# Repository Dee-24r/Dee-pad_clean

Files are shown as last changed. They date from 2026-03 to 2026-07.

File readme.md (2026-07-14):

This is the clean folder (omiting junk and system files) for https://github.com/Dee-24r/My_Hackpad (which I'm still pushing files to by the way).

# Deepad
I'm currently still assembling my macropad and updating the repo as I do.

## Overview
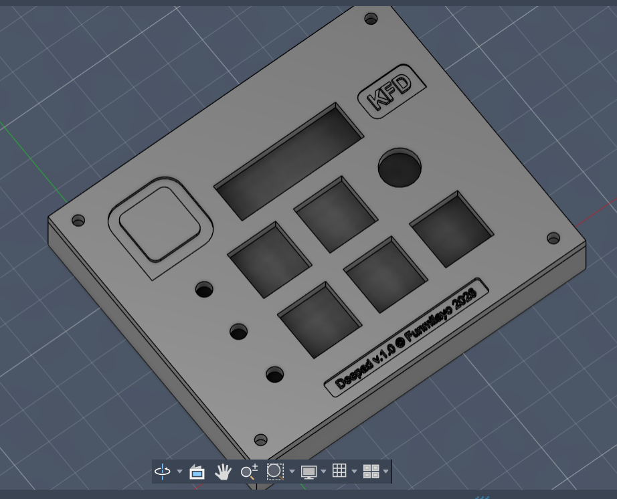
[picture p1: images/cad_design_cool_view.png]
 <br><br>
My macropad contains 5 key switches, a rotary encoder with a switch, an OLED display, and 3 RGB LEDs. It uses the [SEEED Xiao RP2040](https://wiki.seeedstudio.com/XIAO-RP2040/) microcontroller.

## Demo Video
<video width="100%" controls muted playsinline>
	<source src="Macropad%20Demo.mp4" type="video/mp4">
	Your browser does not support embedded video.
</video>

[Macropad Demo.mp4](Macropad%20Demo.mp4)

## Assembly Progress
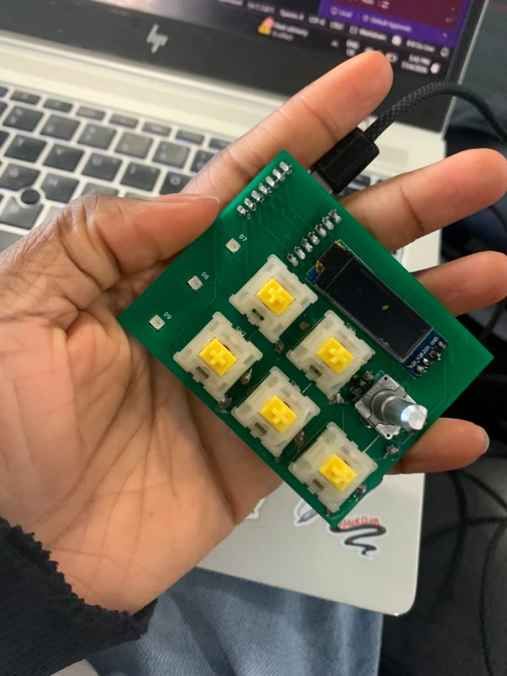
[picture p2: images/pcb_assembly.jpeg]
PCB Assembly

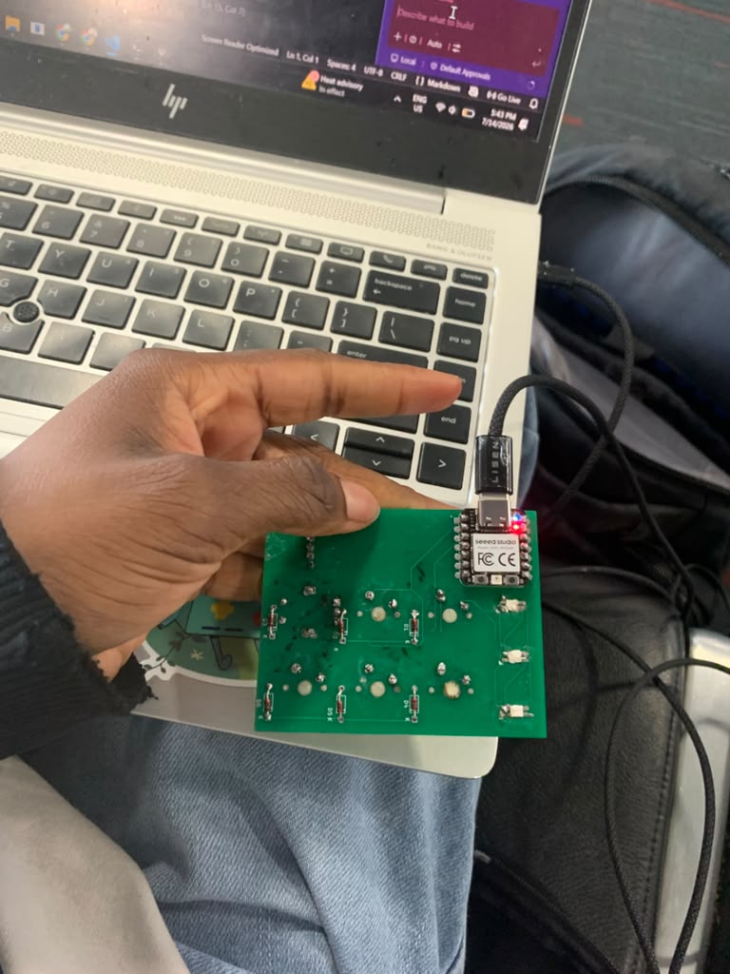
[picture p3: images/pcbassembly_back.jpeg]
PCB Assembly Back


## Repo info

This repo contains the design files (electrical and cad) for deepad v.1.0, :) my macropad. I added the schematic and pcb designs (along with the (custom) symbol and footprint libraries used), the case and pcb cad designs (in .STEP files), gerber files for pcb production (gerber.zip), and the firmware for the macropad. There is also an image folder (If you're scooping around, this is what you should open - it contains screenshots of every important file/design, and so does this README).

[Go to cad files](deepad_cad/)<br>
[Go to firmware](deepad_firmware/)<br>
[Go to schematic and pcb](deepad_sch_and_pcb/)<br>
[View screenshot of all files](images/) This is where you want to go!

## Making my macropad - with pics
I tried to make this to be journal-like cuz I enjoyed doing it. I hope I was detailed enough!

Components I designed it with:
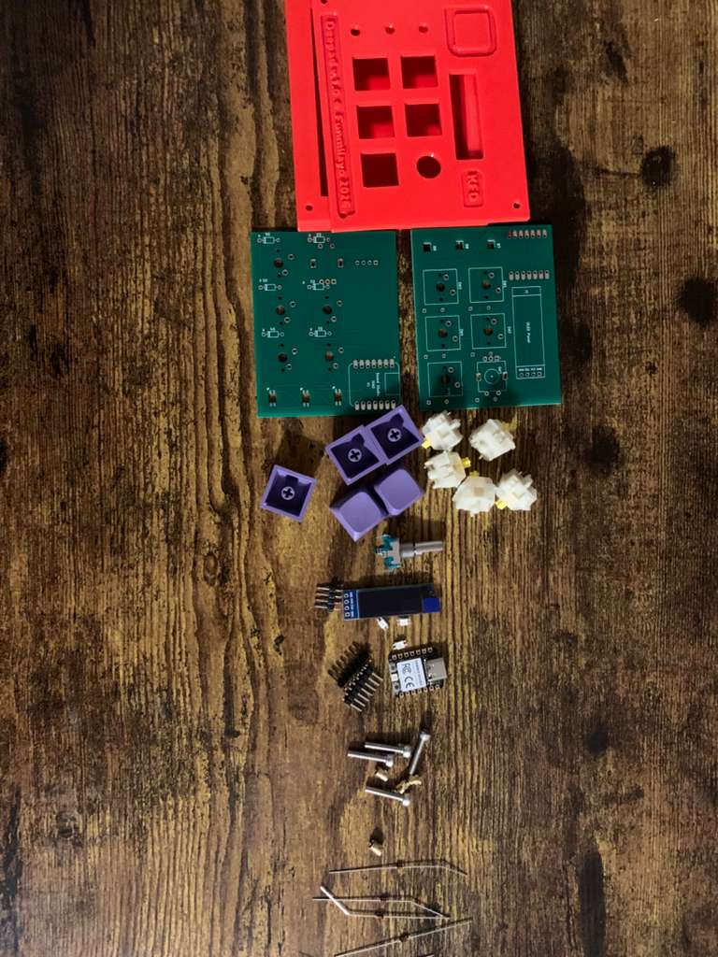
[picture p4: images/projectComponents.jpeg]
Components
 <br><br>

- 1x unsoldered Seeed XIAO RP2040 - the microcontroller
- 5x MX-Style switches - basically keys (keyboard keys)
- 1x EC11 Rotary encoder - it's like a knob and produces rotational value
- 1x 0.91 inch OLED display - display screen
- 5x white blank DSA keycaps - keycaps for the keys
- 3x SK6812 MINI-E LEDs - these are rgb leds
- 4x M3x16mm screws - for screwing my top and bottom case together
- 4x M3x5mx4mm heatset inserts - same as last one - they go together
- 6x 1N4148 diodes -  for the keys

I began by designing the schematic and pcb: added all my components and wired them.

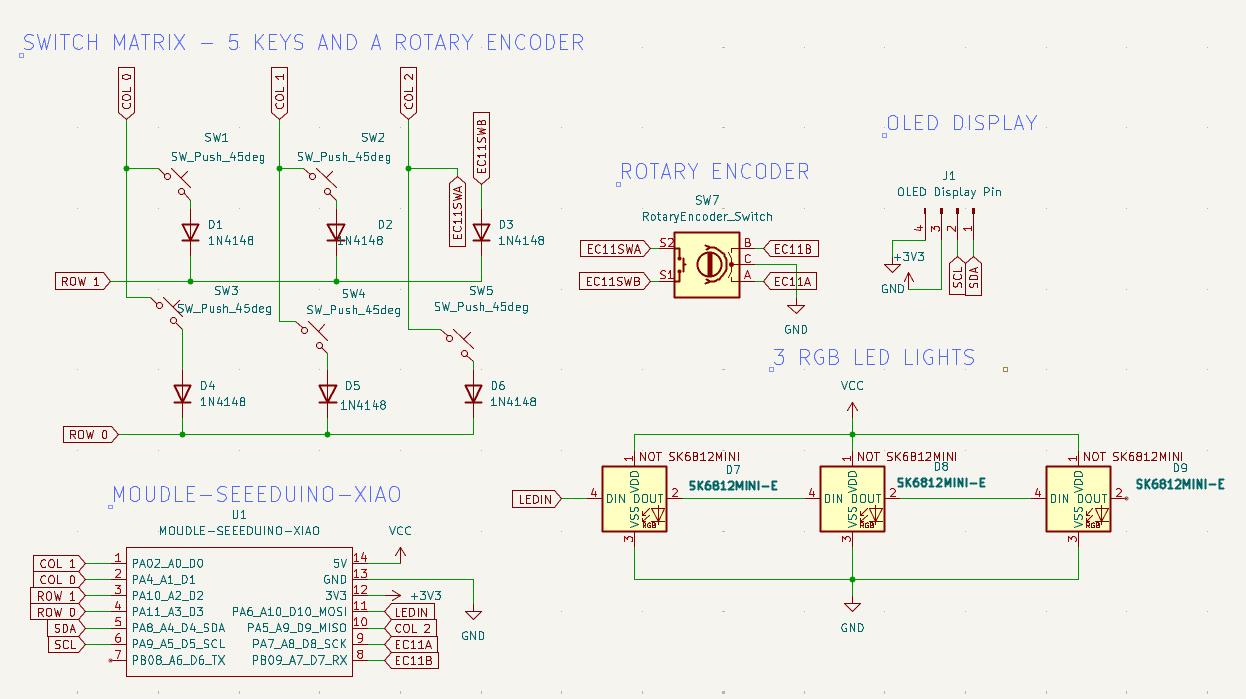
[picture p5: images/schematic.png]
Schematic Screenshot


I assigned footprints and routed the PCB, and learned to use vias. I added edge cuts and exported my STEP file to use in Fusion 360.

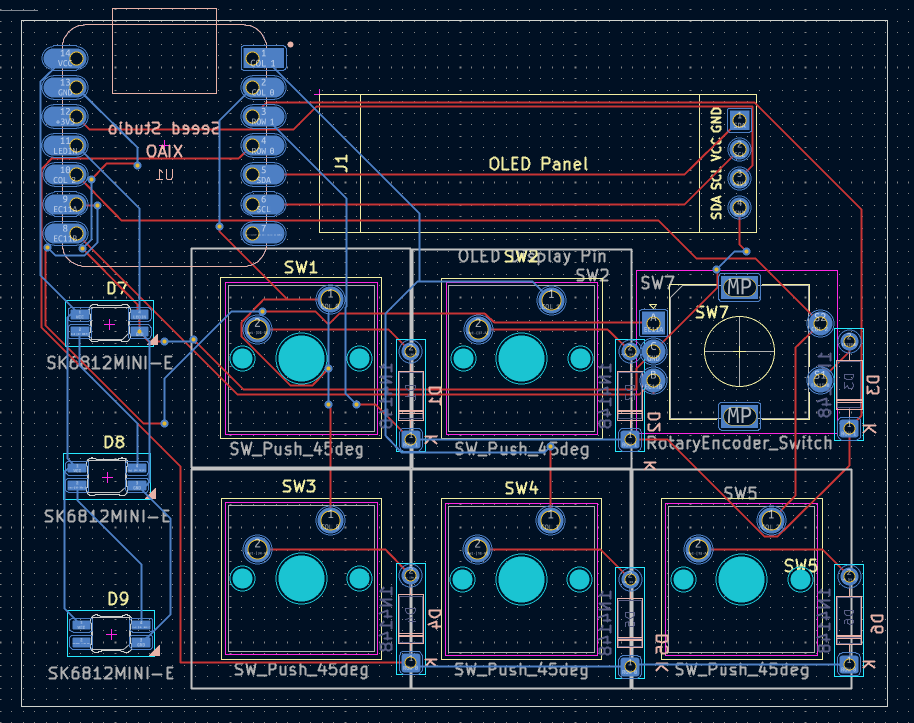
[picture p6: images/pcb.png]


And these are 3d views of the pcb (front and back)

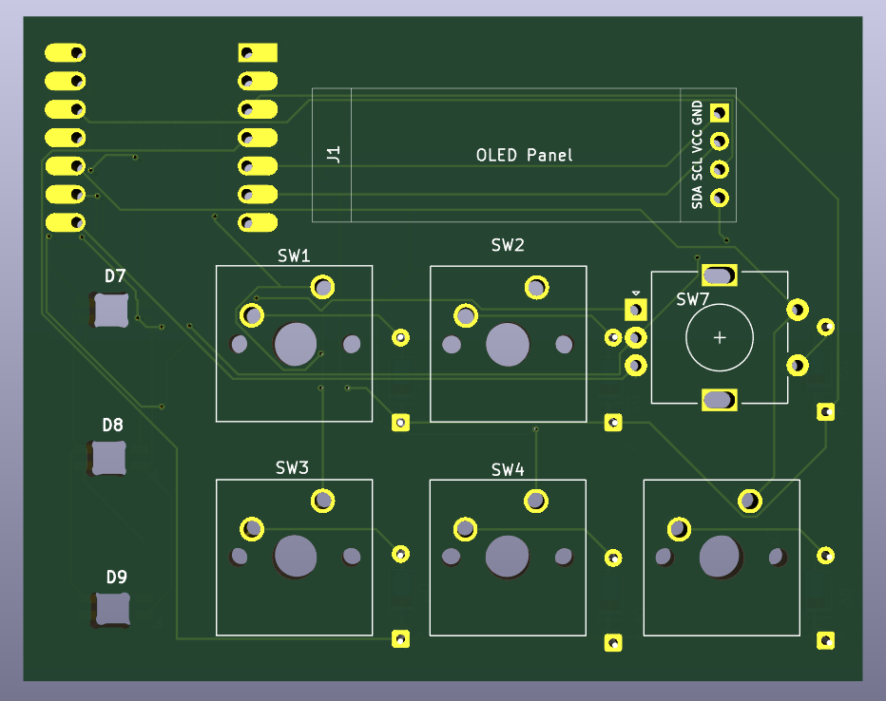
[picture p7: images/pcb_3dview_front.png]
PCB 3d view front Screenshot

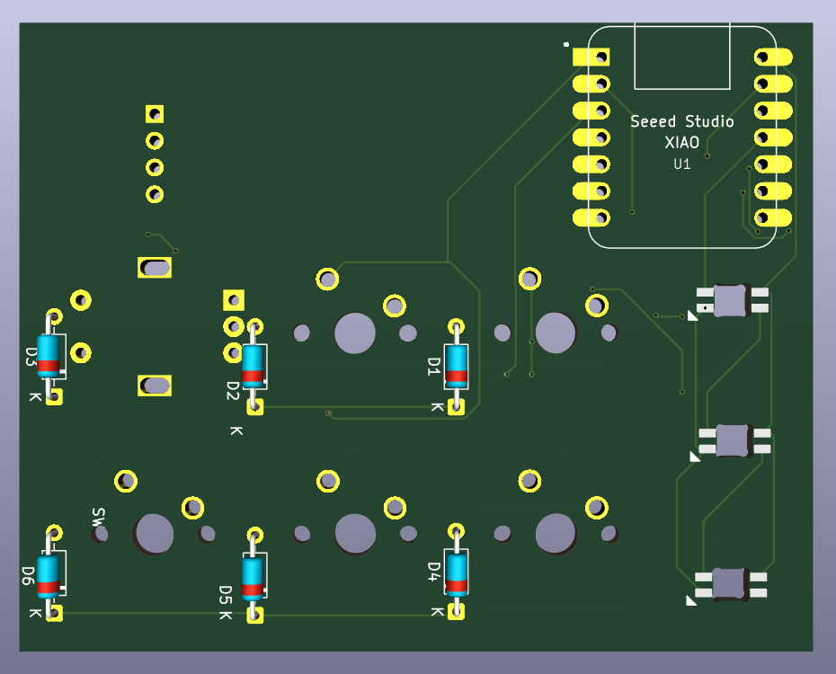
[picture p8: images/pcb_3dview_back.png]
PCB 3d view back Screenshot


BRUH! If you're thinking everything went smooth and step by step, This was not the case! :)

Fusion 360 was a hassle! It's not a bad software; I just didn't know how to use it. But I'm glad I learned.

I started by drawing rectangles for the base of my case, adding holes for the screws and then extruding the shape - outer part of the case is 13mm deep and the inner is 3mm thick. I then attached my PCB .step file to "project" (I had so much trouble understanding how this worked) but got through it anyways. I projected my base case (not recursion :|) to make my top case, which was also 3mm thick. I rounded all my edges a bit and then added the holes for the keys and other components. Finally I added the usb cutout and extruded all holes. I later came back to add a few text decorations to the design (creative enough -- chee!) Here's my full cad design:

CAD screenshot

Next stage was the firmware! You can open up [the firmware folder](deepad_firmware/) to see all the code. It conatins the keyboard.json, rules.mk, config.h, and keymap.c files (keymap.c will still be edited to match my key functions).

I used QMK MSYS to create the folder and then edited the code to match my keys and board. And that was it!

I've soldered most of the parts onto my board. I've actually made more progress after this picture. I'll update the repo later.

Everything I did, I did with the help of many friends in the stasis and blueprint channels, and with much *searching online and asking AI many many many questions*. I'm happy with my work and can't wait to start using it!!

## Macropad use
My first idea for the controls are Git commands in VSCode or any other IDE (e.g. buttons to stage, to commit, push, pull, and more). I plan to have the RGB LEDs indicate information like the status of your branch. Same for the OLED display.

I also would love to see what I can do with this when I hack up a game - (coming soon)! My macropad is made compatible with via, so I'll be using it for many things for sure.

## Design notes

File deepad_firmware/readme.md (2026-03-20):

# deepad
I'm still editing this readme.

Deepad contains 5 keys, a rotary encoder (along with the switch, so we hve 6 switches), 3 rgb leds, and an OLED display. It will be compatible with VIA.

- Keyboard Maintainer: [Oluwafunmilayo Oshebeyo](https://github.com/Dee-24r)
- Processor: RP2040
- Bootloader: rp2040
- Matrix: 2 rows x 3 cols, COL2ROW
- Repository URL: [myHackpad](https://github.com/Dee-24r/myHackpad)

## Features Enabled

- VIA
- OLED (SSD1306)
- RGB Lighting (WS2812)
- Rotary Encoder (with encoder map)
- Media/Mouse key support
- NKRO
 
## Pin Mapping

- Matrix columns: GP27, GP26, GP4
- Matrix rows: GP29, GP28
- Encoder A/B: GP2, GP1
- WS2812 data: GP3 (It's the SK6812MINI-E in the macropad itself)
- OLED I2C SDA/SCL: GP6, GP7

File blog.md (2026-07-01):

## soldering for the first time

Soldering for the rist time and decided to wear shorts for the process :/
Well guess how that went!!

I got my first burn scar on the first day. Anyways, it counts for the experience; scars are a champion's markkks!! (yh sumn lyk that)

I started off by soldering the key/switches (if i remmeber correctly), and thought to myself "is this really necessaryy?"

So, I started soldering the LED's and burnt the back of two. It doesn't affect the connectivity tho!

On my second day of doldering, I melted a part of a socket in the house. Nothing terrible tho, thankfully.

I then soldered the OLED display. When ddesigning a different product 'EDGE' that I needed OLED displays for, I realised that I had designed my OLED display wrongly for the macropad. But I had already soldered the OLED :/

I maybe gave up for a week, thinking the oled would blow up if I soldered the microcontroller. well, I still think that, so I still haven't soldered my micro, which is the only thing currently remaining!!

After a couple weeks, I tried desoldering the OLED with my solder iron. I spent at lest two hours. Even after it looked like all the solder was removed, it was not!! I tried yanking her out, and it didn't work AT ALL!

I hereby am in need of flux!!!! More interestingly I have a highly oxidated :), I have maybe three bridges :) and my joints look like ummmm... :) (see pics). THEREFORE, I AM IN NEED OF FLUXXXX!

More updates coming soon!

#### Here are pics of the soldering statee and details!!
Please, do well to zoon in on the front of the OLED :(

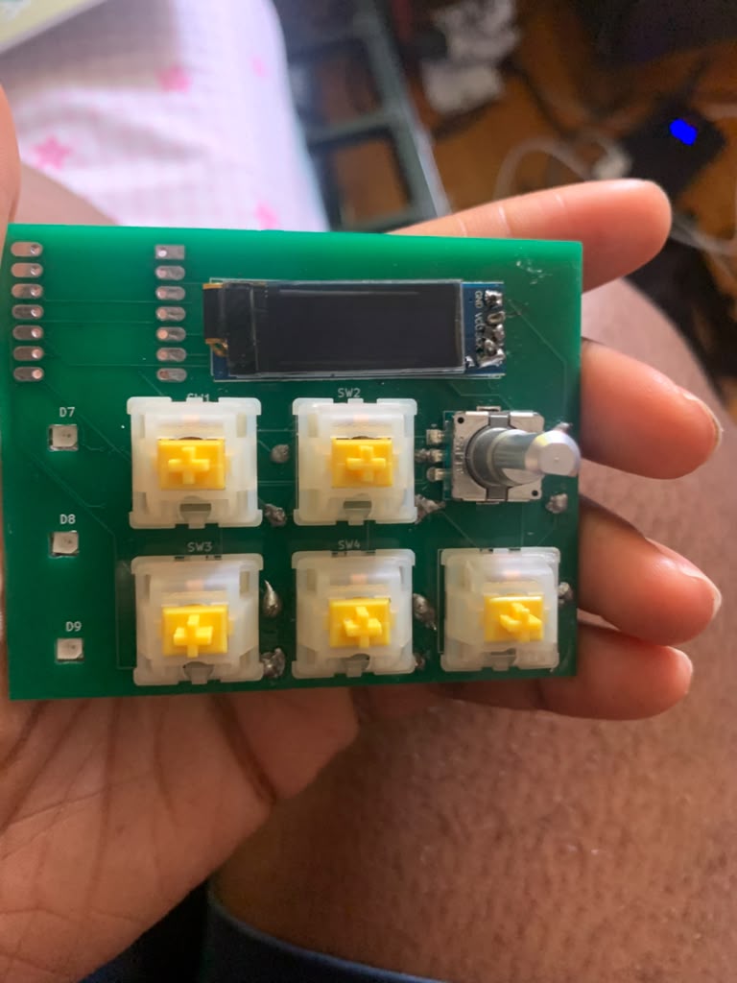
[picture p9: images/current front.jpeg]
Current front


Look at those yummy joints :(
    
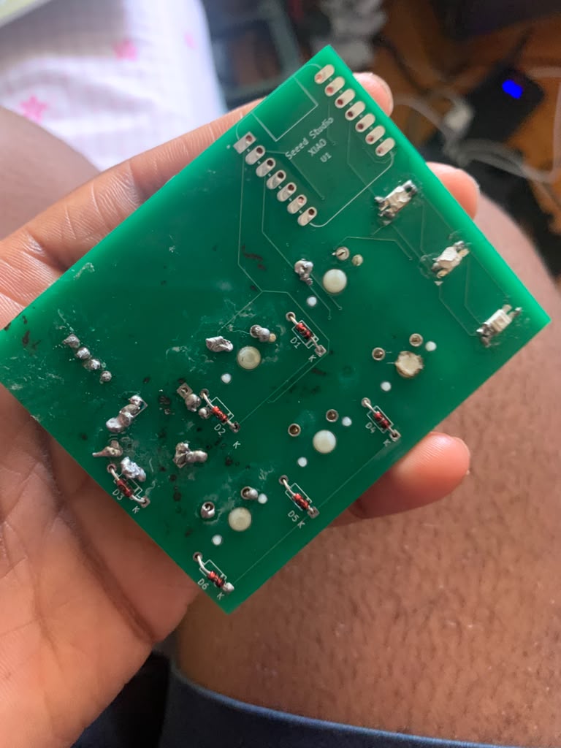
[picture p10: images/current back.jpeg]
Current back


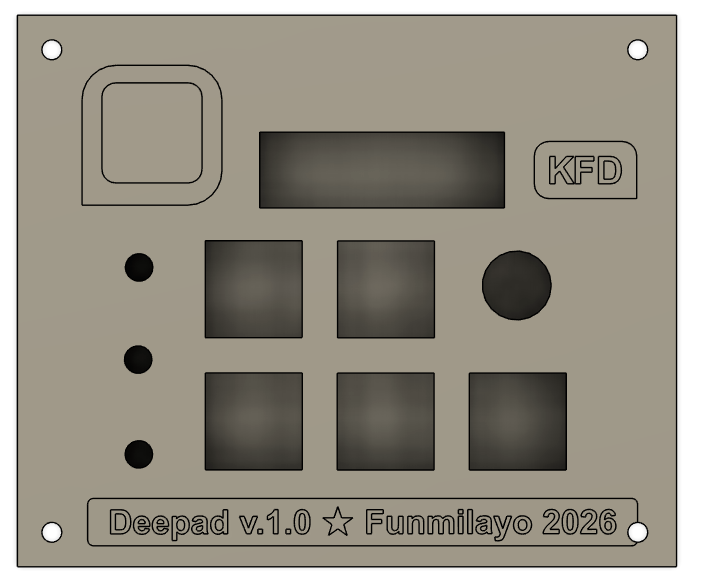
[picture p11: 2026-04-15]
images/cad_design.png

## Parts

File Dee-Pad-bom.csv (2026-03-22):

Name | Purpose | Quantity | Total Cost (USD) | Link | Distributor
1N4148 D0-35 diodes | To use with my switches in the key matrix | 10 | 0.47 | https://www.digikey.com/en/products/detail/onsemi/1N4148/458603 | Digikey
3D printed case | The case for my macropad | 1 | 6.00 | https://app.slack.com/client/E09V59WQY1E/C083P4FJM46 | Printing Legion
PCB fabrication and shipping | My fabricated pcb - the base for the macropad | 1 | 6.32 | https://trade.jlcpcb.com/checkout/payMethod/?unionSettleId=ef6227353eb342a4b2aa266e4f1f0516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 | JLCPCB
Ali Express shipping and fees | Shipping | 1 | 2.27 | https://www.aliexpress.us/p/trade/confirm.html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 | Ali Express
Digikey tax and shipping | Shipping | 1 | 7.84 | https://www.digikey.com/ordering/Ship | Digikey
M3x5mx4mm heatset inserts | secure threading for the M3 screw | 99 | 0.99 | https://www.aliexpress.us/item/2255800046543591.html | Ali Express
M3x16mm screws | Secures top and bottom parts of the cases together | 10 | 1.04 | https://www.aliexpress.us/item/3256805692722422.html | Ali Express
1u Key caps | The covering for the keys | 10 | 2.33 | https://www.aliexpress.us/item/3256807312571573.html | Ali Express
5-pin PCB-mount switch | The keyboard keys | 10 | 2.68 | https://www.aliexpress.us/item/3256806239135691.html?curPageLogUid=wFaqavLZ7pag | Ali Express
5V SK6812MINI-E rgb leds | Shows colours to indicate signals | 10 | 2.83 | https://www.aliexpress.us/item/3256805154503907.html?mp=1 | Ali Express
0.91 inch SSD1306 I2C 128x32 OLED display | Displays information and animations | 1 | 1.79 | https://www.alibaba.com/product-detail/p_1601269142088.html?mark=google_shopping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 | Ali Express
EC11E Rotary encoder | Rotational input and a push button | 1 | 4.49 | https://www.digikey.com/en/products/detail/alps-alpine/EC11E18244AU/19529126?gclsrc=aw.ds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 | Digikey
Seed Xiao - RP2040 | Microcontroller - the power source and control | 1 | 4.68 | https://www.digikey.com/en/products/detail/seeed-technology-co-ltd/102010428/14672129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..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 | Digikey

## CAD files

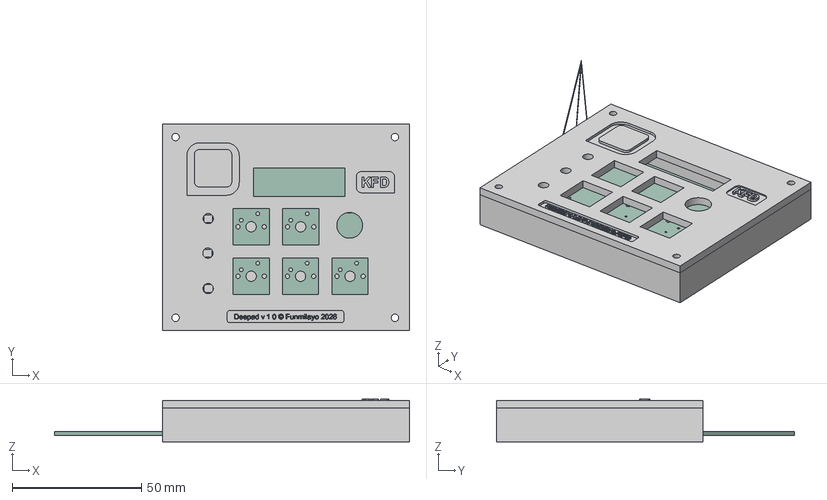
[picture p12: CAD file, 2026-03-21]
deepad_cad/STEP_and_source_files/deepad_full_design.step
137.5 x 115.6 x 16.5 mm

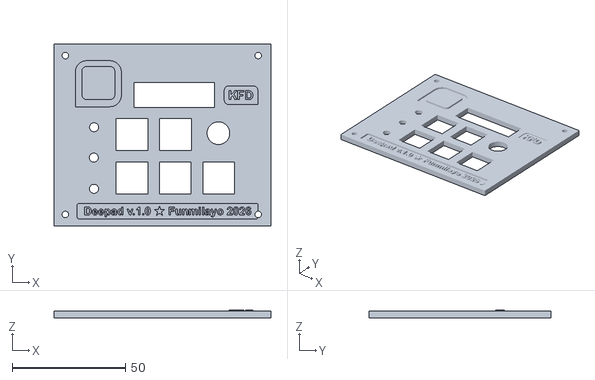
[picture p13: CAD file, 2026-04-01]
deepad_cad/STL files/newest_top_case.stl
95.6 x 80.0 x 3.50

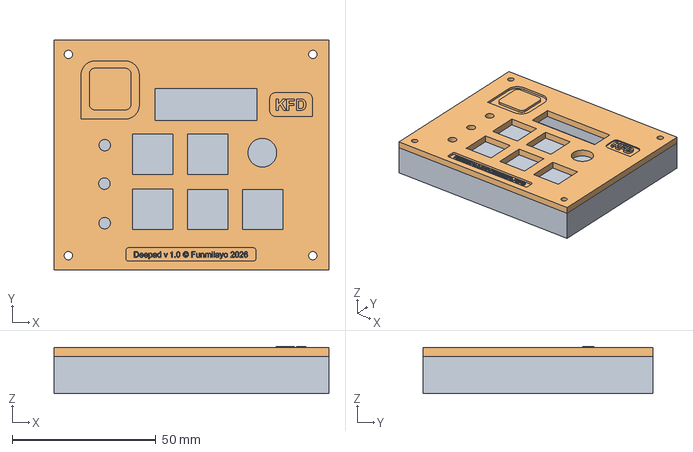
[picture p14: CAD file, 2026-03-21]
deepad_cad/STEP_and_source_files/CASE.step
95.6 x 80.0 x 16.5 mm

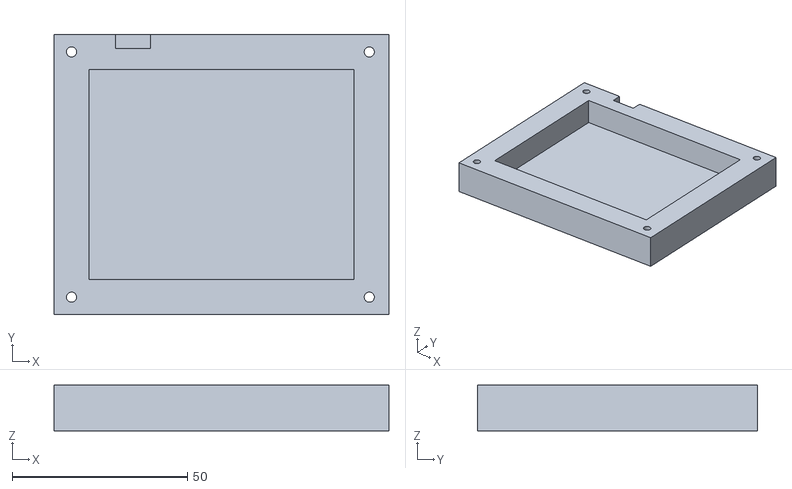
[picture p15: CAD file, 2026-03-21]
deepad_cad/STL files/case_bottom.stl
95.6 x 80.0 x 13.0

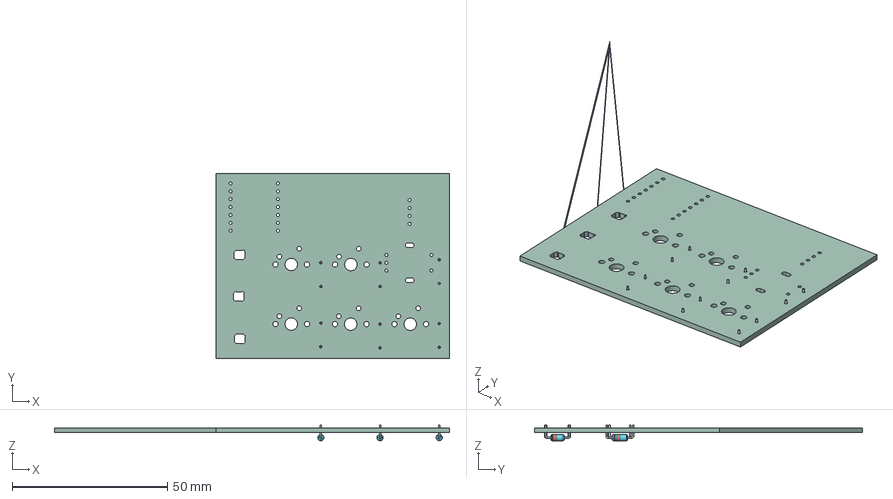
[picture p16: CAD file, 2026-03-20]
deepad_cad/STEP_and_source_files/pcb.step
127.1 x 105.6 x 5.01 mm
D_DO-35_SOD27_P7.62mm_Horizontal x 6
myHackpad_PCB

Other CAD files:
deepad_cad/STEP_and_source_files/deepad.f3z

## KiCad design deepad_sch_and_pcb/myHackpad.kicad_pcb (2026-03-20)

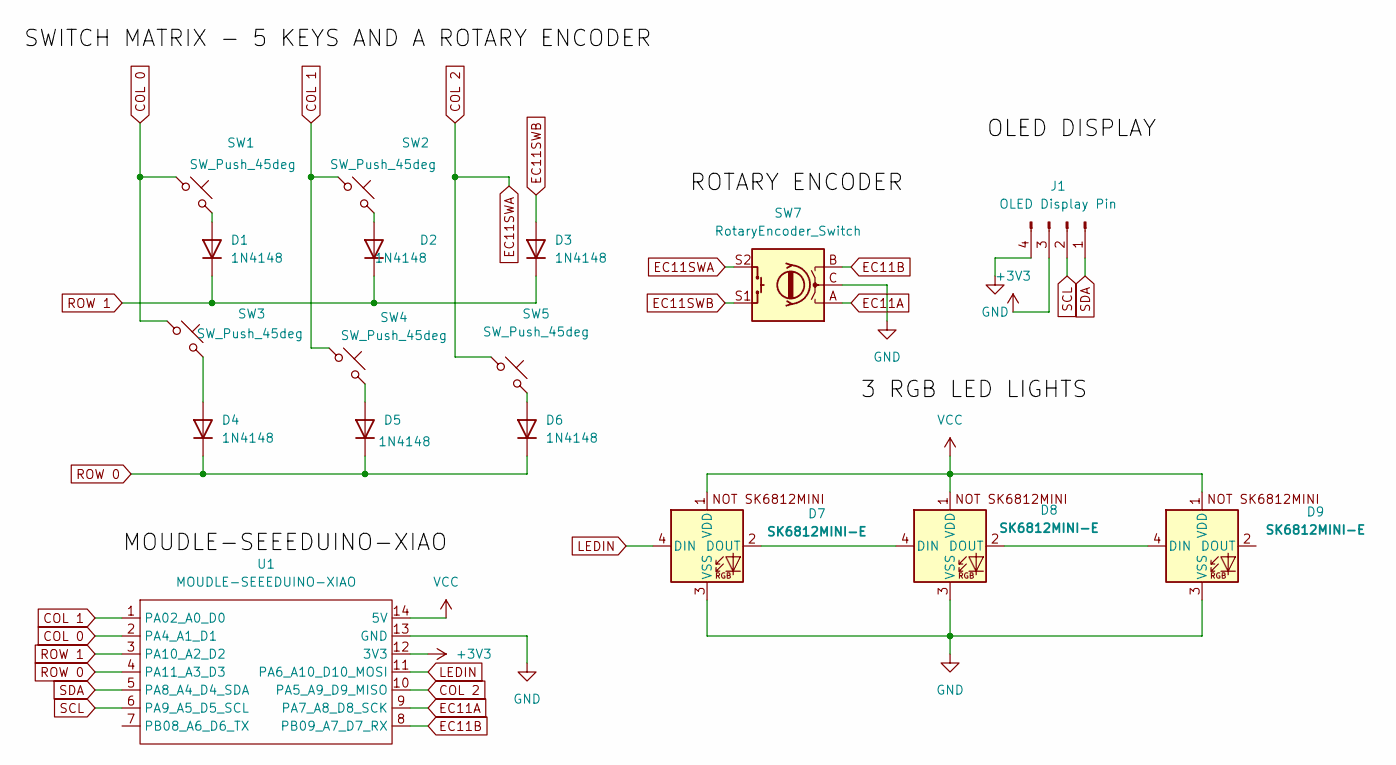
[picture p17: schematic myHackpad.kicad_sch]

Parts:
D1, D2, D3, D4, D5, D6: 1N4148; D_DO-35_SOD27_P7.62mm_Horizontal
D7, D8, D9: SK6812MINI-E; SK6812MINI-E_fixed
J1: OLED Display Pin; SSD1306-0.91-OLED-4pin-128x32
SW1, SW2, SW3, SW4, SW5: SW_Push_45deg; SW_Cherry_MX_1.00u_PCB
SW7: RotaryEncoder_Switch; RotaryEncoder_Alps_EC11E-Switch_Vertical_H20mm
U1: MOUDLE-SEEEDUINO-XIAO; XIAO-Generic-Hybrid-14P-2.54-21X17.8MM

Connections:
+3V3: J1.3, U1.12 (3V3)
COL 0: SW1.1, SW3.1, U1.2 (PA4_A1_D1)
COL 1: SW2.1, SW4.1, U1.1 (PA02_A0_D0)
COL 2: SW5.1, SW7.S2, U1.10 (PA5_A9_D9_MISO)
EC11A: SW7.A, U1.9 (PA7_A8_D8_SCK)
EC11B: SW7.B, U1.8 (PB09_A7_D7_RX)
EC11SWB: D3.2 (A), SW7.S1
GND: D7.3 (VSS), D8.3 (VSS), D9.3 (VSS), J1.4, SW7.C, U1.13 (GND)
LEDIN: D7.4 (DIN), U1.11 (PA6_A10_D10_MOSI)
unnamed: D1.2 (A), SW1.2
unnamed: D2.2 (A), SW2.2
unnamed: D4.2 (A), SW3.2
unnamed: D5.2 (A), SW4.2
unnamed: D6.2 (A), SW5.2
unnamed: D7.2 (DOUT), D8.4 (DIN)
unnamed: D8.2 (DOUT), D9.4 (DIN)
ROW 0: D4.1 (K), D5.1 (K), D6.1 (K), U1.4 (PA11_A3_D3)
ROW 1: D1.1 (K), D2.1 (K), D3.1 (K), U1.3 (PA10_A2_D2)
SCL: J1.2, U1.6 (PA9_A5_D5_SCL)
SDA: J1.1, U1.5 (PA8_A4_D4_SDA)
VCC: D7.1 (VDD), D8.1 (VDD), D9.1 (VDD), U1.14 (5V)

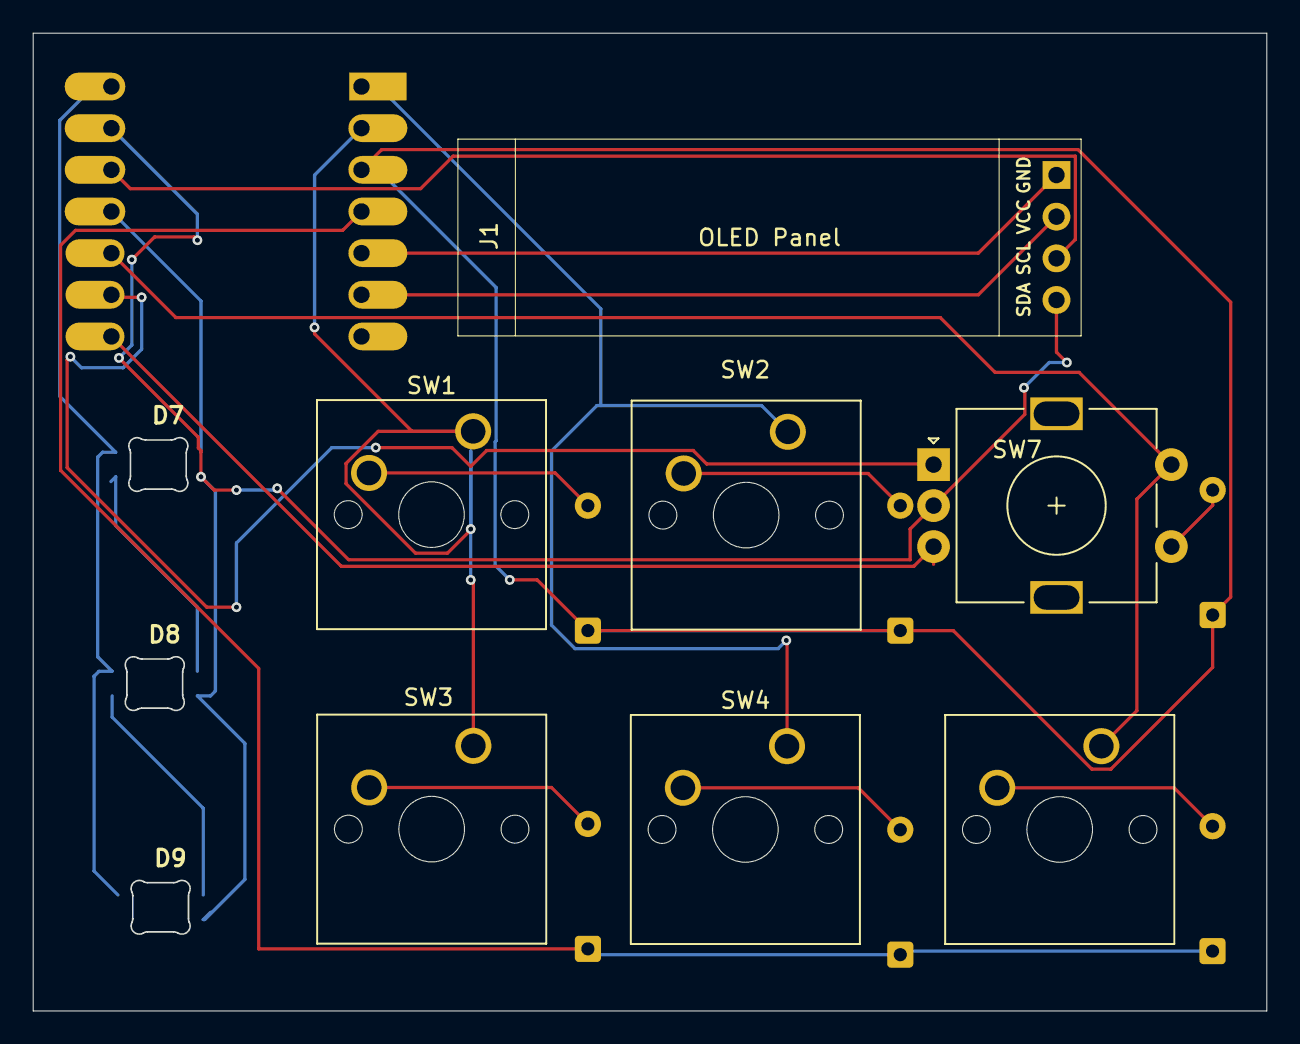
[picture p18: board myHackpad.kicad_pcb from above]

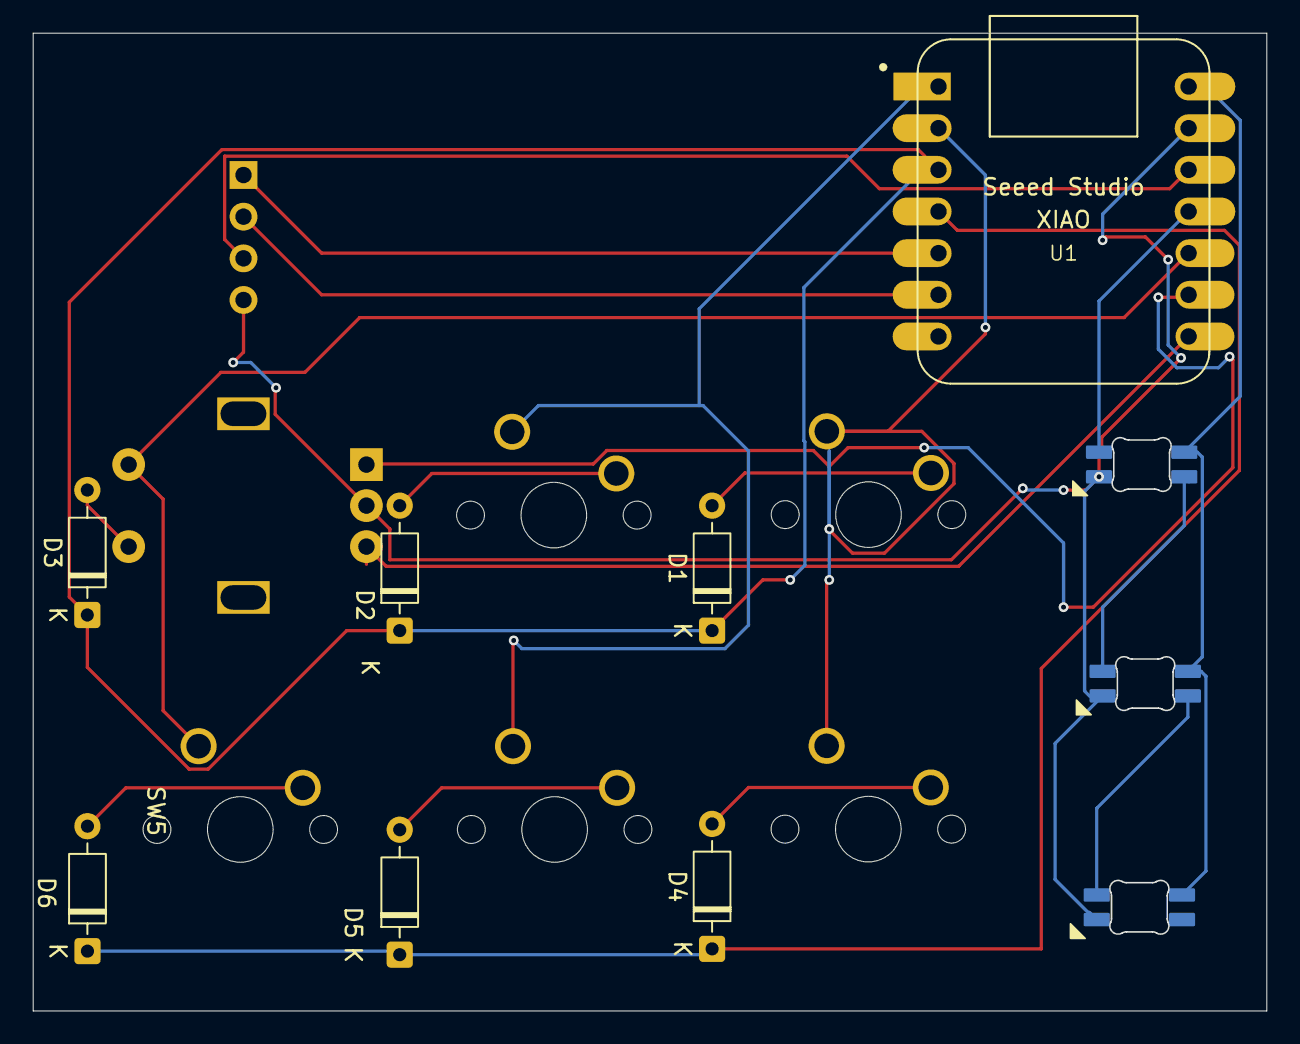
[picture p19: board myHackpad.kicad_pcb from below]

Board: 2 copper layers, 75.2 x 59.6 mm, 17 parts (7 on the bottom side), 21 nets.

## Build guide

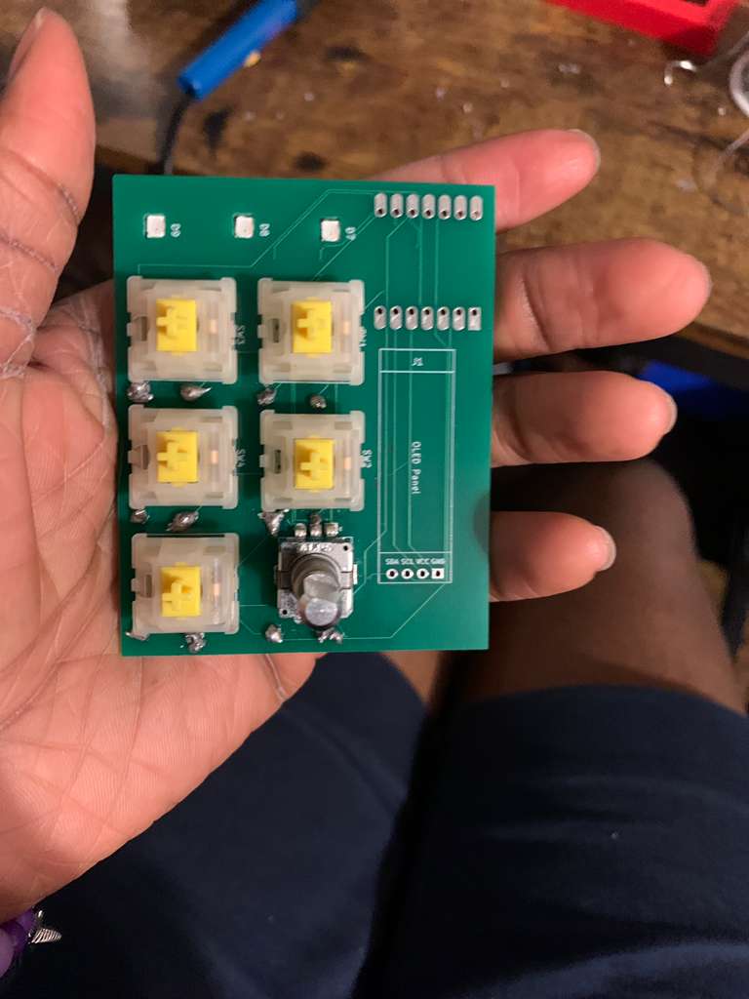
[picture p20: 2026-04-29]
images/pcbassemblyprogress27th.jpeg

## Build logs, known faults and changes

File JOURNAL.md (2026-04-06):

<!--
  This journal is auto generated by Stasis.
-->

# 3/21/2026 5 AM - CAD design + Finishing touches

_Time spent: 3h_

I locked in the entire day (Friday - it's already Saturday midnight) to get this project done and shipped!

Extra CAD Design
---
I know I said I was done, but of course, the case looked plain without designs. I added extruded text designs to make it look more custom and cool.

Submission
---
After looking through the instructions, I created my Gerber files with help from a YT video and the requirement documentation from JLCPCB's website.

Next, I searched up all the components on AliExpress and Digikey. I spent at least an hour searching for components as I needed to make sure they were right. By asking AI questions and dropping screenshots, I was able to confirm that the components I picked were the precise ones. I added my components to the BOM, exported the .csv file, organised files and folders in the repo (I had began this before already), and started writing my README, as well as this journal. (It's currently 1 a.m.!)

Reflections:)
---
I gats say I'm really grateful I'll be able to build a hardware project for free! It was an amazing journey building, and I learned how to use all the tools for next time. This took me the space of 4 weeks from start to finish. If I were to replicate it, tho I'm pretty sure I could get it done in 2 hours (at least if Fusion 360 cooperates). I really enjoyed building this, and I can't wait to start soldering and assembling. Also looking forward to building more projects and heading to Texas this summer. TYSM Statis!








# 3/20/2026 6 PM - CASE DESIGN + Done with Macro!

_Time spent: 3h_

"Victory is mine", she creams as she sighs a sigh of relief. I'm so happy that I got this done with. Yayy! My macropad is finished!

So for the case design, I followed design instructions used to build a different case and got inspo from a YT video as well, as this was my first time using Fusion 360. **Base of the case**: I had 2 rectangles laid down (like offsets) and added holes for the screws between them. Then, I extruded the outer rectangle by 13mm and the inner by 3mm (after much struggle!). I then attached my PCB .step file to "project" (I had so much trouble understanding how this worked) but got through it anyways. I first projected the back of my case design to make another body 3mm thick for the **front/cover of my case** which I moved to the front afterward. I rounded my edges a bit. and then started adding holes while researching how to. Finally I cut out the usb cutout and extruded all the holes.

All in all, after multiple struggles with fusion 360, I finally learnt a few tips (like that extrude-cut needs a negative distance!). I'm really happy with my resilience :) and more importantly that I'm done with my macropad! Yayy








# 3/20/2026 2 PM - Firmware for my macropad

_Time spent: 2h_

**Writing firmware with QMK MSYS**

6 a.m.!! I was up till 6 a.m. last Thursday trying to "project" the holes for the key plate in fusion 360. After more hours of trying, I decided to do the firmware part first. I was confused for the most part until I locked in today to finish it.

To get it done, I was studying a reference macropad made by a hackclubber, following two YouTube tutorials, and asking AI many many questions! At the end, I was able to understand most of the things in the files, such as the matrix pins and the layout matching in the .json file.

I used QMK MSYS to generate a new keyboard folder for me. Then, with all my research from AI, YT videos and reference firmware, I was able to match the dummy code MSYS made to my macropad. I then cross-checked with ChatGPT, even if it gave me many wrong instructions at first.

The key functions in my keymap.c will still be tweaked (especially the key functions). Overall, I'm happy with my progress. Now, I'm going back to Fusion 360 to complete my case design.








# 3/14/2026 2 AM - DESIGN PHASE: VISUALISATION, SCHEMATIC AND PCB DESIGN

_Time spent: 5.5h_

I spent way over 5 hours on the PCB and schematic design, but because I initially planned to submit the project to Blueprint, I didn't know I would need journal entries until now (most hours were tracked with kicad-wakatime). This is my first hardware project, and I've spent about 6 days across 2 weeks designing the schematic and PCB. I began by following the tutorial, which used 3 keyboard keys. I then added 2 more switches (along with diodes for the matrix), a rotary encoder, 3 RGB LED lights, and an OLED display. 

I was following a not-so-detailed tutorial, reverse engineering the orpheuspad design (it's different from my design), and getting much help from the #blueprint channel. The schematic design was the easiest part of this stage, and the hardest part was aligning the switches in the PCB editor, for which I had to convert grid to 0.1mm to finally get it done. I ran out of space while I was routing the PCB, until someone explained "via" to me. I stayed up till 6 am my time working on routing (July 13th) because sometimes when I clicked the PCB after clicking "v", the wiring would exit - extremely annoying.

I learned to use the editors, tho! Can't wait to finish this project and make more.










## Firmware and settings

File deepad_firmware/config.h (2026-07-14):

//Encoder
#define ENCODER_A_PINS { GP2 }
#define ENCODER_B_PINS { GP1 }

//RGB
#define WS2812_DI_PIN GP3 //heard it uses the same protocol as ws2812
#define RGBLIGHT_LED_COUNT 3

//OLED (I2C)
#define I2C_DRIVER I2CD1
#define I2C1_SDA_PIN GP6
#define I2C1_SCL_PIN GP7

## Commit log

2026-03-20 added all files
    [case_design.stp, myHackpad.kicad_pcb, myHackpad.kicad_sch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]
2026-03-21 CAD design update and more files
    [Dee-Pad-bom.csv, case_design.stp, deepad.stp]
2026-03-21 .wakatime-project file
    [pcb.step]
2026-03-21 Changes in STEP files, added STL files
    [CASE.step, case_bottom.stl, case_top.stl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]
2026-03-21 BOM update
    [Dee-Pad-bom.csv]
2026-03-21 Updated BOM
    [Dee-Pad-bom.csv]
2026-03-22 Added diodes to BOM
    [Dee-Pad-bom.csv]
2026-03-24 updated pcb pic
2026-04-01 changed top case and its stl file
    [case_top.stl, newest_top_case.stl]
2026-10-28 a second video
    Corrected the title of the demo video section and added a new section for Git commands with Arduino code.
